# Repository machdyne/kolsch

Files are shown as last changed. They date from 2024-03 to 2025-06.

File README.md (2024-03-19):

# Kölsch Computer

Kölsch is an FPGA computer based on the GateMate A1.

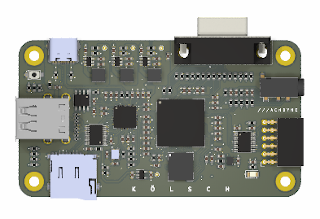
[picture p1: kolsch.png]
Kölsch Computer


This repo contains schematics, PCB layouts, pinouts, a 3D-printable case, example gateware and documentation.

Find more information on the [Kölsch product page](https://machdyne.com/product/kolsch-computer/).

## Programming Kölsch 

Kölsch can be programmed over USB-C or by copying gateware to a MicroSD card. The FPGA is configured by the onboard RP2040, which can load the configuration from onboard flash, a FAT-formatted MicroSD card or over the USB-JTAG bridge.

### JTAG

Program the FPGA configuration SRAM:

```
openFPGALoader -c dirtyJtag image.bit
```

## Examples

In order to build the examples, first edit rtl/config.mk and set the paths to the location of your toolchain. You can download the toolchain from [Cologne Chip](https://colognechip.com).

You can build each example with:

```
$ make && make impl
```

### 3.5mm TRRS Audio Jack

| Pin | Signal |
| --- | --- |
| T | Left Audio |
| R1 | Right Audio |
| R2 | Composite Video |
| S | GND |

## Resources

 * [fpga-dac audio player](https://github.com/machdyne/fpga-dac)

## Board Revisions

| Revision | Notes |
| --- | ----- |
| V2 | Initial production version |

## Funding

This project was partially funded through the NGI0 Entrust Fund, a fund established by NLnet with financial support from the European Commission's Next Generation Internet programme.

## License

This project is released under the [CERN-OHL-P](LICENSE.txt) license.

Note: You can use these designs for commercial purposes but we ask that instead of producing exact clones, that you either replace our trademarks and logos with your own or add your own next to ours.

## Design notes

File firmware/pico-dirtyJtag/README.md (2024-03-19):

# PICO-DIRTYJTAG

This code allows the Pico to become a JTAG cable.  It uses the PIO unit to produce and capture the JTAG signals.  This is a port of the excellent [DirtyJtag project](https://github.com/jeanthom/DirtyJTAG)

An additional feature provides a bridge to an external UART.  This is often useful when the target provides debugging output or a console over a UART.

<<<<<<< HEAD
| Pin name | Pico GPIO | Werkzeug GPIO |
|:---|:---|:---|
| TDI | GPIO16 | GPIO1 |
| TDO | GPIO17 | GPIO2 |
| TCK | GPIO18 | GPIO0 |
| TMS | GPIO19 | GPIO3 |
| RST | GPIO20 | GPIO4 |
| TRST | GPIO21 | GPIO5 |
=======
## Pinout
>>>>>>> 737c7b169514ec51a2ec9919f7796557875f9240

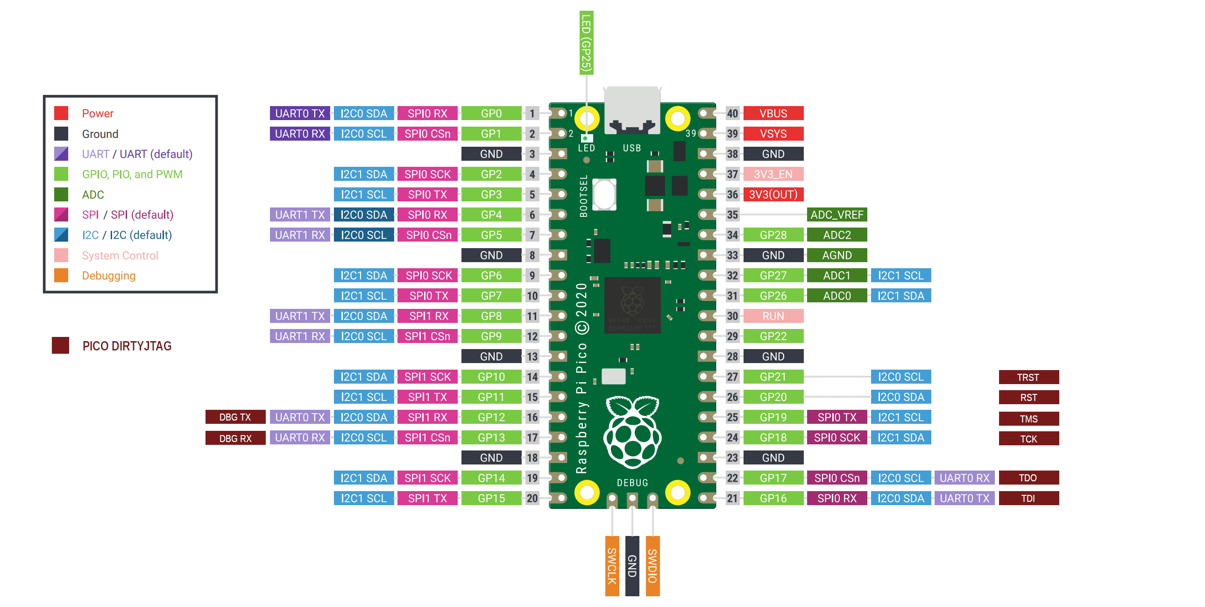
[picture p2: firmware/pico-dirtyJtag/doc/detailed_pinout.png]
Pinout image


| Pin name | GPIO | Pico Pin Number |
|:---|:---| - |
| TDI | GPIO16 | 21 |
| TDO | GPIO17 | 22 |
| TCK | GPIO18 | 24 |
| TMS | GPIO19 | 25 |
| RST | GPIO20 | 26 |
| TRST | GPIO21 | 27 |
| DBG TX | GPIO12 | 16 |
| DBG RX | GPIO13 | 17 |

## Configuration

Other configurations and RP2040 boards are supported.  

In `dirtyJtagConfig.h`, select the board you want to use, or define a new one.

``` C
#define BOARD_TYPE BOARD_PICO
//#define BOARD_TYPE BOARD_ADAFRUIT_ITSY
//#define BOARD_TYPE BOARD_SPOKE_RP2040
//#define BOARD_TYPE BOARD_WERKZEUG
//#define BOARD_TYPE BOARD_QMTECH_RP2040_DAUGHTERBOARD
```

The following values control where the code expects to find functionality.  Of course, not all pins can can be used for all functions.  Take care, especially with the UART pins, to ensure compatibility.

``` C
#define PIN_TDI 16 
#define PIN_TDO 17
#define PIN_TCK 18
#define PIN_TMS 19
#define PIN_RST 20
#define PIN_TRST 21

#define LED_INVERTED   0
#define PIN_LED_TX     25
#define PIN_LED_ERROR  25
#define PIN_LED_RX     25

#define PIN_UART       uart0
#define PIN_UART_TX    12
#define PIN_UART_RX    13
```

If the CDC to UART bridge is not required, or interfers in any way, it can be disabled by setting `USB_CDC_UART_BRIDGE` to 0

``` C
#define USB_CDC_UART_BRIDGE  0
```

See the `dirtyJtagConfig.h` file for these and other configuration options.

## Building pico-dirtyJtag

Follow [the instructions](https://github.com/raspberrypi/pico-sdk) for installing the official Raspberry Pi Pico SDK, then clone this repository and use the following commands:

```
mkdir -p build
cd build
cmake ..     # or for Werkzeug: cmake -DWERKZEUG=ON ..
make
```

If everything succeeds you should have a `dirtyJtag.uf2` file that you can directly upload to the Pi Pico.

## JTAG Usage

Once the board is running `pico-dirtyJtag` and connected to your host you will see a new USB device

```
$ lsusb
...
Bus 003 Device 112: ID 1209:c0ca Generic Jean THOMAS DirtyJTAG
...
```

You can connect to JTAG functionality using `UrJTAG`, `openFPGALoader` or other JTAG tools.  Depending on how your system is set up, you may have to run these commands as root.

For example, using `openFPGALoader`, the following command will connect to the Pico and read the IDCODE from the attached device:

```
> sudo openFPGALoader --cable dirtyJtag --detect
Jtag frequency : requested 6000000Hz -> real 6000000Hz
index 0:
	idcode 0x1112043
	manufacturer lattice
	family ECP5
	model  LFE5UM-45
	irlength 8
```

`UrTag` use is similar:

```
$ sudo jtag

UrJTAG 2021.03 #d9a2943f
Copyright (C) 2002, 2003 ETC s.r.o.
Copyright (C) 2007, 2008, 2009 Kolja Waschk and the respective authors

UrJTAG is free software, covered by the GNU General Public License, and you are
welcome to change it and/or distribute copies of it under certain conditions.
There is absolutely no warranty for UrJTAG.

warning: UrJTAG may damage your hardware!
Type "quit" to exit, "help" for help.

jtag> cable dirtyjtag
jtag> detect
IR length: 8
Chain length: 1
Device Id: 01000001000100010010000001000011 (0x41112043)
  Manufacturer: Lattice Semiconductors (0x043)
  Part(0):      LFE5U-45F-CABGA256 (0x1112)
  Stepping:     0
  Filename:     /usr/local/share/urjtag/lattice/lfe5u-45f-cabga256/lfe5u-45f-cabga256
jtag> 
```

## Debug UART

Once connected, a new port appears as an additional USB interface.  This port can be opened from a terminal emulation program or by custom code.

```
$ ls -la /dev/tty*
...
crw-rw---- 1 root  dialout 166,  0 May 28 08:25 /dev/ttyACM0
...
```

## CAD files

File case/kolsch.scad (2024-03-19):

/*
 * Kölsch Case
 * Copyright (c) 2023 Lone Dynamics Corporation. All rights reserved.
 *
 * required hardware:
 *  - 4 x M3 x 25mm countersunk bolts
 *  - 4 x M3 nuts
 *
 */

$fn = 100;

board_width = 50;
board_length = 90;
board_height = 1.6;
board_spacing = 2;

wall = 1.5;

top_height = 19;
bottom_height = 6;

mdq_board();

translate([0,0,15])
	mdq_case_top();

translate([0,0,-15])
	mdq_case_bottom();

module mdq_board() {
	
	difference() {
		color([0,0.5,0])
			roundedcube(board_width,board_length,board_height, 5);
		translate([5, 5, -1]) cylinder(d=3.2, h=10);
		translate([5, 85, -1]) cylinder(d=3.2, h=10);
		translate([85, 5, -1]) cylinder(d=3.2, h=10);
		translate([85, 85, -1]) cylinder(d=3.2, h=10);
	}	
	
}

module mdq_case_top() {

	difference() {
				
		union() {
			color([0.5,0.5,0.5]) {
				roundedcube(board_width+(wall*2),board_length+(wall*2),top_height, 5);
	//			translate([-1,45,0]) cube([board_width+5, 5,16]);
	//			translate([-1,65,0]) cube([board_width+5, 5,16]);
	//			translate([-1,55,0]) cube([board_width+5, 5,16]);
	//			translate([-1,45,0]) cube([board_width+5, 5,16]);
	//			translate([50/2-10,-1,0]) cube([5, board_length+5,16]);
	//			translate([50/2-1.25,-1,0]) cube([5, board_length+5,16]);
			}
		}
		
		// cutouts
			
		translate([2,9.5,-2])
			roundedcube(board_width-1.25,board_length-16,18.75,2.5);

		translate([9.5,3,-2])
			roundedcube(board_width-16,board_length-3,10.25,2.5);
		
		translate([wall, wall, 0]) {

			// vents
			translate([25-12.5,75-0.5,0]) cube([25,1,20]);
			translate([25-12.5,65-0.5,0]) cube([25,1,20]);
			translate([25-12.5,55-0.5,0]) cube([25,1,20]);

			translate([-5,55-0.5,5]) cube([10,1,10]);
			translate([-5,45-0.5,5]) cube([10,1,10]);
			translate([-5,35-0.5,5]) cube([10,1,10]);
			translate([-5,25-0.5,5]) cube([10,1,10]);
			translate([-5,15-0.5,5]) cube([10,1,10]);
			
			translate([45,65-0.5,5]) cube([10,1,10]);
			translate([45,60-0.5,5]) cube([10,1,10]);
			translate([45,55-0.5,5]) cube([10,1,10]);
			translate([45,50-0.5,5]) cube([10,1,10]);
			translate([45,45-0.5,5]) cube([10,1,10]);
						
			
			// VGA
			translate([30,90-65.29-(31/2),-1]) cube([30,31,12.5+1]);
		
			// PMOD
			translate([50-32.5-(16/2),-5,-1]) cube([16,30,5+1]);
			
			// audio jack
			translate([50-15-(6.2/2),-5,-1]) cube([6.2,30,5+1]);

			// USBC
			translate([30,90-14.325-(9.5/2),-1]) cube([30,9.5,3.5+1]);
			
			// USBA
			translate([25-(16/2),70,0]) cube([16,50,15.7+1]);
		
			// SD
			translate([-5,90-17.5-(15/2),-1]) cube([30,15,2+1]);

			// bolt holes
			translate([5, 5, -21]) cylinder(d=3.5, h=40);
			translate([5, 85, -21]) cylinder(d=3.5, h=40);
			translate([45, 5, -20]) cylinder(d=3.5, h=40);
			translate([45, 85, -21]) cylinder(d=3.5, h=40);

			// flush mount bolt holes
			translate([5, 5, top_height-1.5]) cylinder(d=5.25, h=4);
			translate([5, 85, top_height-1.5]) cylinder(d=5.25, h=4);
			translate([45, 5, top_height-1.5]) cylinder(d=5.25, h=4);
			translate([45, 85, top_height-1.5]) cylinder(d=5.25, h=4);
							
			// kolsch text
			rotate(270)
				translate([-25,22.5,top_height-0.5])
					linear_extrude(1)
						text("K Ö L S C H", size=5, halign="center",
							font="Ubuntu:style=Bold");

		}
		
	}	
}

module mdq_case_bottom() {
	
	difference() {
		color([0.5,0.5,0.5])
			roundedcube(board_width+(wall*2),board_length+(wall*2),bottom_height, 5);
		
		// cutouts
		translate([3,10,1.5])
			roundedcube(board_width-3,board_length-17,10,2.5);
				
		translate([10.5,2.5,1.5])
			roundedcube(board_width-17.5,board_length-2,10,2.5);

		translate([wall, wall, 0]) {
			
		// board cutout
		translate([0,0,bottom_height-board_height])
			roundedcube(board_width+0.2,board_length+0.2,board_height+1,2.5);

		translate([wall, wall, 0]) {

			// USBC
			translate([38.5,53.8-(9.5/2),5]) cube([10,9.5,10.5+1]);
			
		}

		// bolt holes
		translate([5, 5, -11]) cylinder(d=3.2, h=25);
		translate([5, 85, -11]) cylinder(d=3.2, h=25);
		translate([45, 5, -11]) cylinder(d=3.2, h=25);
		translate([45, 85, -11]) cylinder(d=3.2, h=25);

		// nut holes
		translate([5, 5, -1]) cylinder(d=7, h=4, $fn=6);
		translate([5, 85, -1]) cylinder(d=7, h=4, $fn=6);
		translate([45, 5, -1]) cylinder(d=7, h=4, $fn=6);
		translate([45, 85, -1]) cylinder(d=7, h=4, $fn=6);

		}
		
	}	
}

// https://gist.github.com/tinkerology/ae257c5340a33ee2f149ff3ae97d9826
module roundedcube(xx, yy, height, radius)
{
    translate([0,0,height/2])
    hull()
    {
        translate([radius,radius,0])
        cylinder(height,radius,radius,true);

        translate([xx-radius,radius,0])
        cylinder(height,radius,radius,true);

        translate([xx-radius,yy-radius,0])
        cylinder(height,radius,radius,true);

        translate([radius,yy-radius,0])
        cylinder(height,radius,radius,true);
    }
}

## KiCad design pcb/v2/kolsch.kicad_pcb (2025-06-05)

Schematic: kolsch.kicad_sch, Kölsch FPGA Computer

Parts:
C1, C2, C3, C12, C16, C18, C19, C27, C28, C38, C39, C48, C49, C69, C70: 2.2uF; C_0603_1608Metric
C4, C5, C6, C21, C22, C29, C30, C41, C42, C50, C51, C75, C76: 470nF; C_0603_1608Metric
C7: 220nF; C_0402_1005Metric
C8, C9, C10, C11, C15, C17, C23, C24, C31, C32, C33, C34, C35, C43, C44, C45, C46, C47, C52, C53, C55, C56, C78, C79, C80, C81, C103, C104, C105, C106, C107: 100nF; C_0402_1005Metric
C13, C14, C25, C26: 10nF; C_0402_1005Metric
C20, C36, C37, C58, C59, C61, C62, C64, C65, C66, C67, C68, C71, C74, C77, C82, C84, C86, C87: 100nF; C_0603_1608Metric
C40, C72, C73, C97, C98, C101: 10uF; C_0603_1608Metric
C54, C57: 15pF; C_0603_1608Metric
C60, C63, C83, C85, C88: 1uF; C_0603_1608Metric
C89, C90, C91: 4.7uF; C_0603_1608Metric
C92: 10uF; R_0603_1608Metric
C93: 100nF; R_0603_1608Metric
C94, C95, C96: 10pF; C_0603_1608Metric
C99, C100, C102: 22uF; C_0603_1608Metric
C109, C110: 10uF; C_0402_1005Metric
D1: LED; LED_1206_3216Metric
FB3, FB4, FB5: Ferrite_Bead; R_0603_1608Metric
H1, H2, H3, H4: MountingHole_Pad; MountingHole_3.2mm_M3_Pad
J1: TYPE-C-31-M-12-FIXED; USB_C_Receptacle_HRO_TYPE-C-31-M-12-BIG-PADS-PASTE; PARTREV A
J2: USB_A_Stacked; USB_A_Wuerth_61400826021_Horizontal_Stacked
J3: AudioJack4; Jack_3.5mm_PJ320D_Horizontal
J4: MICROSD; SDCARD
L1, L2, L3: 2.2uH; L_Taiyo-Yuden_MD-4040
PMOD1: PMOD-Device-x2-Type-1A-GPIO; PMOD_2x06_HOST
R1, R3, R4, R5, R8: 4K7; R_0603_1608Metric
R2, R10: 5K1; R_0603_1608Metric
R6, R7: 27R; R_0603_1608Metric
R9, R17, R18, R26, R27, R28, R29, R40, R41: 0R; LD-NETTIE-0603
R11, R12, R20, R21: 15K; R_0402_1005Metric
R13, R14, R15, R16: 22R; R_0402_1005Metric
R19, R58, R65: 200K; R_0603_1608Metric
R30, R35, R38, R45, R49, R53: 1K; R_0603_1608Metric
R31, R32, R63, R64: 100R; R_0603_1608Metric
R33, R42, R43, R47, R51: 270R; R_0603_1608Metric
R34, R44, R48, R52: 536R; R_0603_1608Metric
R36: 2K; R_0603_1608Metric
R37: 10K; R_0603_1608Metric
R39: 33R; R_0603_1608Metric
R46, R50, R54: 2K2; R_0603_1608Metric
R55, R56, R57: 68R; R_0603_1608Metric
R59, R60, R61, R62: 20K; R_0603_1608Metric
R66: 44K2; R_0603_1608Metric
R67: 150K; R_0603_1608Metric
R68: 47K; R_0603_1608Metric
R69: 100K; R_0603_1608Metric
R70: 120K; R_0603_1608Metric
R73: 22R; R_0603_1608Metric
SW1: BOOT; Button_2P_3x4mm
TP1: TP_PWR1V8; TestPoint_THTPad_D1.0mm_Drill0.5mm
TP2: TP_PWR3V3; TestPoint_THTPad_D1.0mm_Drill0.5mm
TP3: TP_PWR2V5; TestPoint_THTPad_D1.0mm_Drill0.5mm
TP4: TP_PWR1V1; TestPoint_THTPad_D1.0mm_Drill0.5mm
U1: CCGM1A1; BGA-324_15.0x15.0mm_Layout18x18_P0.8mm_Ball0.5mm_Pad0.4mm_N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
U2: W989D6DBGX6; W989D6DB; PARTREV A05
U3, U8: LSF0108PWR; TSSOP-20_4.4x6.5mm_P0.65mm
U4: RP2040; RP2040-QFN-56-OFFICIAL; PARTREV 1.6.1
U5: AT25FF321A-SSHN-B; SOIC-8_3.9x4.9mm_P1.27mm
U6: 48MHz; OSC_KC2016Z13.5600C1KX00
U7: NCP164ASN180T1G; SOT-23-5
U9, U10, U11: TLV62569DDC; SOT-23-6
VGA1: DB15_Female_MountingHoles; DSUB-15-HD_Female_Horizontal_P2.29x1.98mm_EdgePinOffset3.03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
Y1: ECS-80-12-33-JGN-TR-12MHZ; XTAL_ECS-240-8-33-AGN-TR

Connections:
/AUDIO_L: R31.1, U1.A9 (IO_NB_B0)
/AUDIO_LC: C72.1, J3.T
/AUDIO_R: R32.1, U1.B9 (IO_NB_A0)
/AUDIO_RC: C73.1, J3.R1
/BOOT: R38.1, SW1.1
/CDONE: U1.V3 (IO_WA_B2/CFG_DONE), U4.27 (GPIO16)
/CFAILED: R1.2, U1.V2 (IO_WA_A2/~CFG_FAILED), U4.28 (GPIO17)
/CFG_MD2: U1.U4 (CFG_MD2/IO_WA_A1), U4.18 (GPIO15)
/CFG_MD3: U1.V4 (CFG_MD3/IO_WA_B1), U4.17 (GPIO14)
/CLK48: U1.N14 (CLK0/IO_SB_A8), U6.3 (CLK)
/CRESET: U1.T15 (~RESET), U4.11 (GPIO8)
/CSD_MISO: U1.E2 (IO_WC_B3), U3.6 (A4), U4.6 (GPIO4)
/CSD_MOSI: U1.E1 (IO_WC_A3), U3.5 (A3), U4.9 (GPIO7)
/CSD_SCK: U1.E3 (IO_WC_A4), U3.4 (A2), U4.8 (GPIO6)
/CSD_SS: U1.D2 (IO_WC_B5), U3.3 (A1), U4.7 (GPIO5)
/CUSB1_DN: U1.H2 (IO_WB_B7), U3.10 (A8), U4.13 (GPIO10)
/CUSB1_DP: U1.H1 (IO_WB_A7), U3.9 (A7), U4.14 (GPIO11)
/CUSB2_DN: U1.K2 (IO_WB_B5), U3.8 (A6), U4.15 (GPIO12)
/CUSB2_DP: U1.K1 (IO_WB_A5), U3.7 (A5), U4.16 (GPIO13)
/DRAM_A0: U1.K18 (IO_EA_A2), U2.H7 (A0)
/DRAM_A1: U1.P18 (IO_SB_B2), U2.H8 (A1)
/DRAM_A2: U1.N15 (IO_SB_B8), U2.J8 (A2)
/DRAM_A3: U1.K17 (IO_EA_B2), U2.J7 (A3)
/DRAM_A4: U1.M14 (IO_EA_B0), U2.J3 (A4)
/DRAM_A5: U1.M15 (IO_EA_A0), U2.J2 (A5)
/DRAM_A6: U1.P15 (IO_SB_B6), U2.H3 (A6)
/DRAM_A7: U1.M17 (IO_SB_A3), U2.H2 (A7)
/DRAM_A8: U1.L16 (IO_EA_A1), U2.H1 (A8)
/DRAM_A9: U1.U18 (IO_SB_B0), U2.G3 (A9)
/DRAM_A10: U1.P17 (IO_SB_A2), U2.H9 (A10)
/DRAM_A11: U1.U17 (IO_SB_A0), U2.G2 (A11)
/DRAM_A12: U1.L15 (IO_EA_B1), U2.G1 (A12)
/DRAM_BS0: U1.J17 (IO_EA_B4), U2.G7 (BA0)
/DRAM_BS1: U1.R18 (IO_SB_B1), U2.G8 (BA1)
/DRAM_CAS: U1.M18 (IO_SB_B3), U2.F7 (~CAS)
/DRAM_CKE: U1.R10 (IO_SA_A7), U2.F3 (CKE)
/DRAM_CLK: U1.R9 (IO_SA_A6), U2.F2 (CLK)
/DRAM_CS: U1.R17 (IO_SB_A1), U2.G9 (~CS)
/DRAM_DQ0: U1.V8 (IO_SA_B5), U2.A8 (DQ0)
/DRAM_DQ1: U1.T8 (IO_SA_B4), U2.B9 (DQ1)
/DRAM_DQ2: U1.U8 (IO_SA_A5), U2.B8 (DQ2)
/DRAM_DQ3: U1.P13 (IO_SB_B7), U2.C9 (DQ3)
/DRAM_DQ4: U1.T10 (IO_SA_B7), U2.C8 (DQ4)
/DRAM_DQ5: U1.P14 (CLK2/IO_SB_A6), U2.D9 (DQ5)
/DRAM_DQ6: U1.T9 (IO_SA_B6), U2.D8 (DQ6)
/DRAM_DQ7: U1.V10 (IO_SA_B8), U2.E9 (DQ7)
/DRAM_DQ8: U1.R7 (IO_SA_A2), U2.E1 (DQ8)
/DRAM_DQ9: U1.R8 (IO_SA_A4), U2.D2 (DQ9)
/DRAM_DQ10: U1.T7 (IO_SA_B2), U2.D1 (DQ10)
/DRAM_DQ11: U1.V5 (IO_SA_B0), U2.C2 (DQ11)
/DRAM_DQ12: U1.U5 (IO_SA_A0), U2.C1 (DQ12)
/DRAM_DQ13: U1.V7 (IO_SA_B3), U2.B2 (DQ13)
/DRAM_DQ14: U1.T6 (IO_SA_B1), U2.B1 (DQ14)
/DRAM_DQ15: U1.U7 (IO_SA_A3), U2.A2 (DQ15)
/DRAM_LDQM: U1.U10 (IO_SA_A8), U2.E8 (LDQM)
/DRAM_RAS: U1.R14 (IO_SB_B5), U2.F8 (~RAS)
/DRAM_UDQM: U1.R6 (IO_SA_A1), U2.F1 (UDQM)
/DRAM_WE: U1.R13 (CLK3/IO_SB_A5), U2.F9 (~WE)
/JTAG_TCK: R3.2, U1.R3 (JTAG_TCK/IO_WA_A5), U4.29 (GPIO18)
/JTAG_TDI: R5.2, U1.T2 (JTAG_TDI/IO_WA_A4), U4.31 (GPIO20)
/JTAG_TDO: R8.2, U1.U2 (JTAG_TDO/IO_WA_B3), U4.32 (GPIO21)
/JTAG_TMS: R4.2, U1.T3 (JTAG_TMS/IO_WA_B4), U4.30 (GPIO19)
/LED: R42.1, U1.A12 (IO_NB_B4)
/PMOD_A1: U1.D17 (IO_EB_B2), U8.3 (A1)
/PMOD_A1C: PMOD1.1 (IOA0), U8.18 (B1)
/PMOD_A2: U1.D18 (IO_EB_A2), U8.4 (A2)
/PMOD_A2C: PMOD1.2 (IOA1), U8.17 (B2)
/PMOD_A3: U1.E15 (IO_EB_B3), U8.5 (A3)
/PMOD_A3C: PMOD1.3 (IOA2), U8.16 (B3)
/PMOD_A4: U1.E16 (IO_EB_A3), U8.6 (A4)
/PMOD_A4C: PMOD1.4 (IOA3), U8.15 (B4)
/PMOD_A7: U1.F18 (IO_EB_A0), U8.7 (A5)
/PMOD_A7C: PMOD1.7 (IOB0), U8.14 (B5)
/PMOD_A8: U1.F17 (IO_EB_B0), U8.8 (A6)
/PMOD_A8C: PMOD1.8 (IOB1), U8.13 (B6)
/PMOD_A9: U1.F16 (IO_EB_A1), U8.9 (A7)
/PMOD_A9C: PMOD1.9 (IOB2), U8.12 (B7)
/PMOD_A10: U1.F15 (IO_EB_B1), U8.10 (A8)
/PMOD_A10C: PMOD1.10 (IOB3), U8.11 (B8)
/PWR1V0: C58.1, C61.1, C63.1, U4.23 (DVDD), U4.45 (VREG_VOUT), U4.50 (DVDD)
/PWR1V1: C1.2, C2.2, C4.2, C5.2, C9.2, C10.2, C13.2, C14.2, C18.2, C19.2, C20.2, C21.2, C22.2, C23.2, C24.2, C25.2, C26.2, C96.1, C99.1, C100.1, L3.2, R69.1, R73.2, TP4.1, U1.F9 (VDD), U1.G6 (VDD), U1.G8 (VDD), U1.G10 (VDD), U1.G12 (VDD), U1.H7 (VDD), U1.H9 (VDD), U1.H11 (VDD), U1.H13 (VDD), U1.J6 (VDD), U1.J8 (VDD), U1.J10 (VDD), U1.J12 (VDD), U1.K7 (VDD), U1.K9 (VDD), U1.K11 (VDD), U1.K13 (VDD), U1.L6 (VDD), U1.L8 (VDD), U1.L10 (VDD), U1.L12 (VDD), U1.M7 (VDD), U1.M9 (VDD), U1.M11 (VDD), U1.M13 (VDD), U1.N6 (VDD), U1.N8 (VDD), U1.N10 (VDD)
/PWR1V8: C84.1, C88.1, C103.2, C104.2, C105.2, C106.2, C107.2, C109.2, C110.2, R27.2, R28.2, R29.2, TP1.1, U2.A7 (VDDQ), U2.A9 (VDD), U2.B3 (VDDQ), U2.C7 (VDDQ), U2.D3 (VDDQ), U2.E7 (VDD), U2.J9 (VDD), U6.1 (INH), U6.4 (VCC), U7.5 (OUT)
/PWR2V5: C8.2, C16.2, C37.1, C60.1, C62.1, C64.1, C65.1, C68.1, C71.1, C74.1, C77.1, C82.1, C83.1, C87.1, C95.1, C98.1, L2.2, R1.1, R4.1, R5.1, R8.1, R9.2, R17.2, R18.2, R26.2, R40.2, R41.2, R67.1, TP3.1, U1.T14 (VDD_CLK), U3.2 (VREF_A), U4.1 (IOVDD), U4.10 (IOVDD), U4.22 (IOVDD), U4.26 (RUN), U4.33 (IOVDD), U4.42 (IOVDD), U4.43 (ADC_AVDD), U4.44 (VREG_VIN), U4.49 (IOVDD), U5.8 (VCC), U8.2 (VREF_A)
/PWR3V3: C59.1, C85.1, C92.1, C93.1, C94.1, C97.1, C101.1, J4.4 (VDD), L1.2, PMOD1.6 (VCC), PMOD1.12 (VCC), R19.1, R37.1, R58.1, R59.1, R60.1, R61.1, R62.1, R65.1, TP2.1, U4.48 (USB_VDD), U7.1 (IN), U7.3 (EN)
/PWR5V0: C89.1, C90.1, C91.1, FB3.1, FB4.1, FB5.1, U9.1 (EN), U9.4 (VIN), U10.1 (EN), U10.4 (VIN), U11.1 (EN), U11.4 (VIN)
/RP_QSPI_IO0: U4.53 (QSPI_SD0), U5.5 (DI(IO0))
/RP_QSPI_IO1: U4.55 (QSPI_SD1), U5.2 (DO(IO1))
/RP_QSPI_IO2: U4.54 (QSPI_SD2), U5.3 (IO2)
/RP_QSPI_IO3: U4.51 (QSPI_SD3), U5.7 (IO3)
/RP_QSPI_SCK: U4.52 (QSPI_SCLK), U5.6 (CLK)
/RP_QSPI_SS: R37.2, R38.2, U4.56 (QSPI_CSN), U5.1 (~CS)
/RSPI_MISO: U1.P1 (IO_WA_A7/SPI_D1), U4.40 (GPIO28/ADC2)
/RSPI_MOSI: U1.P2 (IO_WA_B7/SPI_D0), U4.39 (GPIO27/ADC1)
/RSPI_SCK: U1.N4 (IO_WA_B8/SPI_CLK), U4.38 (GPIO26/ADC0)
/RSPI_SS: U1.N3 (IO_WA_A8/~SPI_CS), U4.41 (GPIO29/ADC3)
/RUART_RX: U1.F3 (IO_WC_A2), U4.37 (GPIO25)
/RUART_TX: U1.G1 (IO_WC_A0), U4.36 (GPIO24)
/SD_MISO: J4.7 (DAT0), R62.2, U3.15 (B4)
/SD_MOSI: J4.3 (CMD), R60.2, U3.16 (B3)
/SD_SCK: J4.5 (CLK), R61.2, U3.17 (B2)
/SD_SS: J4.2 (DAT3/CD), R59.2, U3.18 (B1)
/SWCLK: U4.24 (SWCLK)
/SWD: U4.25 (SWD)
/USB1_CONN_DN: J2.2 (D1-), R14.1, R21.1
/USB1_CONN_DP: J2.3 (D1+), R13.1, R20.1
/USB1_DN: R14.2, U3.11 (B8)
/USB1_DP: R13.2, U3.12 (B7)
/USB2_CONN_DN: J2.6 (D2-), R12.1, R16.1
/USB2_CONN_DP: J2.7 (D2+), R11.1, R15.1
/USB2_DN: R16.2, U3.13 (B6)
/USB2_DP: R15.2, U3.14 (B5)
/USB_CONN_DN: J1.A7 (DN1), J1.B7 (DN2), R6.1
/USB_CONN_DP: J1.A6 (DP1), J1.B6 (DP2), R7.1
/USB_DN: R6.2, U4.46 (USB_DM)
/USB_DP: R7.2, U4.47 (USB_DP)
/VBUSC: FB3.2, FB4.2, J1.A4 (VBUS), J1.A9 (VBUS), J1.B4 (VBUS), J1.B9 (VBUS)
/VDD_EA: C39.2, C42.2, C44.2, C46.2, R27.1, U1.G14 (VDD_EA), U1.H17 (VDD_EA), U1.J14 (VDD_EA), U1.L14 (VDD_EA), U1.L17 (VDD_EA)
/VDD_EB: C38.2, C41.2, C43.2, C45.2, C47.2, R26.1, U1.A16 (VDD_EB), U1.B18 (VDD_EB), U1.E14 (VDD_EB), U1.E17 (VDD_EB), U1.F13 (VDD_EB)
/VDD_NA: C27.2, C29.2, C31.2, C33.2, C35.2, R17.1, U1.A5 (VDD_NA), U1.B7 (VDD_NA), U1.E6 (VDD_NA), U1.E8 (VDD_NA), U1.F7 (VDD_NA)
/VDD_NB: C28.2, C30.2, C32.2, C34.2, R18.1, U1.B10 (VDD_NB), U1.B13 (VDD_NB), U1.E10 (VDD_NB), U1.E12 (VDD_NB), U1.F11 (VDD_NB)
/VDD_PLL: C7.2, C12.2, C102.2, R73.1, U1.P16 (VDD_PLL)
/VDD_SA: C49.2, C51.2, C53.2, C56.2, R29.1, U1.P6 (VDD_SA), U1.P8 (VDD_SA), U1.P10 (VDD_SA), U1.U6 (VDD_SA), U1.U9 (VDD_SA)
/VDD_SB: C48.2, C50.2, C52.2, C55.2, R28.1, U1.N11 (VDD_SB), U1.N13 (VDD_SB), U1.N18 (VDD_SB), U1.R15 (VDD_SB), U1.T18 (VDD_SB)
/VDD_WA: C3.2, C6.2, C11.2, C15.2, C17.2, R9.1, U1.N5 (VDD_WA), U1.P3 (VDD_WA), U1.P5 (VDD_WA), U1.T1 (VDD_WA), U1.U3 (VDD_WA)
/VDD_WB: C70.2, C76.2, C79.2, C81.2, R41.1, U1.H5 (VDD_WB), U1.J2 (VDD_WB), U1.K5 (VDD_WB), U1.M2 (VDD_WB), U1.M5 (VDD_WB)
/VDD_WC: C69.2, C75.2, C78.2, C80.2, R40.1, U1.A2 (VDD_WC), U1.C2 (VDD_WC), U1.D5 (VDD_WC), U1.F2 (VDD_WC), U1.F5 (VDD_WC)
/VGA_B0: R51.2, U1.C9 (IO_NA_A8)
/VGA_B1: R52.2, U1.C8 (IO_NA_A6)
/VGA_B2: R53.2, U1.C7 (IO_NA_A5)
/VGA_B3: R54.2, U1.C6 (IO_NA_A3)
/VGA_BLUE: R51.1, R52.1, R53.1, R54.1, R57.2
/VGA_B_CONN: R57.1, VGA1.3
/VGA_G0: R47.2, U1.C5 (IO_NA_B2)
/VGA_G1: R48.2, U1.B8 (IO_NA_B7)
/VGA_G2: R49.2, U1.A8 (IO_NA_A7)
/VGA_G3: R50.2, U1.B6 (IO_NA_B4)
/VGA_GREEN: R47.1, R48.1, R49.1, R50.1, R56.2
/VGA_G_CONN: R56.1, VGA1.2
/VGA_HS: R63.2, U1.A3 (IO_NA_A0)
/VGA_HS_CONN: R63.1, VGA1.13
/VGA_R0: R43.2, U1.A6 (IO_NA_A4)
/VGA_R1: R44.2, U1.B5 (IO_NA_A2)
/VGA_R2: R45.2, U1.A4 (IO_NA_A1)
/VGA_R3: R46.2, U1.B4 (IO_NA_B1)
/VGA_RED: R43.1, R44.1, R45.1, R46.1, R55.2
/VGA_R_CONN: R55.1, VGA1.1
/VGA_VS: R64.2, U1.B3 (IO_NA_B0)
/VGA_VS_CONN: R64.1, VGA1.14
/VIDEO_C: J3.R2, R39.2
/VIDEO_D0: R33.1, U1.A17 (IO_EB_B5)
/VIDEO_D1: R34.1, U1.C18 (IO_EB_A4)
/VIDEO_D2: R35.1, U1.C17 (IO_EB_B4)
/VIDEO_D3: R36.1, U1.B15 (IO_EB_A8)
/XIN: C54.2, U4.20 (XIN), Y1.1 (IN/OUT)
/XOUT: R30.2, U4.21 (XOUT)
GND: C1.1, C2.1, C3.1, C4.1, C5.1, C6.1, C7.1, C8.1, C9.1, C10.1, C11.1, C12.1, C13.1, C14.1, C15.1, C16.1, C17.1, C18.1, C19.1, C20.1, C21.1, C22.1, C23.1, C24.1, C25.1, C26.1, C27.1, C28.1, C29.1, C30.1, C31.1, C32.1, C33.1, C34.1, C35.1, C36.2, C37.2, C38.1, C39.1, C40.2, C41.1, C42.1, C43.1, C44.1, C45.1, C46.1, C47.1, C48.1, C49.1, C50.1, C51.1, C52.1, C53.1, C54.1, C55.1, C56.1, C57.2, C58.2, C59.2, C60.2, C61.2, C62.2, C63.2, C64.2, C65.2, C66.2, C67.2, C68.2, C69.1, C70.1, C71.2, C74.2, C75.1, C76.1, C77.2, C78.1, C79.1, C80.1, C81.1, C82.2, C83.2, C84.2, C85.2, C86.2, C87.2, C88.2, C89.2, C90.2, C91.2, C92.2, C93.2, C97.2, C98.2, C99.2, C100.2, C101.2, C102.1, C103.1, C104.1, C105.1, C106.1, C107.1, C109.1, C110.1, D1.1 (K), H1.1, H2.1, H3.1, H4.1, J1.A1 (GND), J1.A12 (GND), J1.B1 (GND), J1.B12 (GND), J1.S1 (SHIELD), J1.S2 (SHIELD), J1.S3 (SHIELD), J1.S4 (SHIELD), J2.4 (GND1), J2.8 (GND2), J2.9 (Shield), J3.S, J4.6 (VSS), PMOD1.5 (GND), PMOD1.11 (GND), R2.2, R3.1, R10.2, R11.2, R12.2, R20.2, R21.2, R66.2, R68.2, R70.2, SW1.2, U1.A1 (GND), U1.A7 (GND), U1.A10 (GND), U1.A13 (GND), U1.A18 (GND), U1.B16 (GND), U1.C1 (GND), U1.E5 (GND), U1.E7 (GND), U1.E9 (GND), U1.E11 (GND), U1.E13 (GND), U1.E18 (GND), U1.F1 (GND), U1.F6 (GND), U1.F8 (GND), U1.F10 (GND), U1.F12 (GND), U1.F14 (GND), U1.G5 (GND), U1.G7 (GND), U1.G9 (GND), U1.G11 (GND), U1.G13 (GND), U1.H6 (GND), U1.H8 (GND), U1.H10 (GND), U1.H12 (GND), U1.H14 (GND), U1.H18 (GND), U1.J1 (GND), U1.J5 (GND), U1.J7 (GND), U1.J9 (GND), U1.J11 (GND), U1.J13 (GND), U1.K6 (GND), U1.K8 (GND), U1.K10 (GND), U1.K12 (GND), U1.K14 (GND), U1.L5 (GND), U1.L7 (GND), U1.L9 (GND), U1.L11 (GND), U1.L13 (GND), U1.L18 (GND), U1.M1 (GND), U1.M6 (GND), U1.M8 (GND), U1.M10 (GND), U1.M12 (GND), U1.M16 (GND), U1.N7 (GND), U1.N9 (GND), U1.N12 (GND), U1.N17 (GND), U1.P4 (GND), U1.P7 (GND), U1.P9 (GND), U1.R5 (CFG_MD0/IO_WA_A0), U1.R12 (GND), U1.R16 (GND), U1.T4 (GND), U1.T5 (CFG_MD1/IO_WA_B0), U1.T11 (GND), U1.T17 (GND), U1.U1 (POR_EN/IO_WA_A3), U1.U14 (GND), U1.U15 (GND), U1.U16 (GND), U1.V1 (GND), U1.V6 (GND), U1.V9 (GND), U1.V14 (GND), U1.V16 (GND), U1.V18 (GND), U2.A1 (VSS), U2.A3 (VSSQ), U2.B7 (VSSQ), U2.C3 (VSSQ), U2.D7 (VSSQ), U2.E3 (VSS), U2.J1 (VSS), U3.1 (GND), U4.19 (TESTEN), U4.57 (GND), U5.4 (GND), U6.2 (GND), U7.2 (GND), U8.1 (GND), U9.2 (GND), U10.2 (GND), U11.2 (GND), VGA1.0 (PAD), VGA1.5, VGA1.6, VGA1.7, VGA1.8, VGA1.10, Y1.2 (GND), Y1.4 (GND)
unnamed: C66.1, C72.2, R31.2
unnamed: C67.1, C73.2, R32.2
unnamed: D1.2 (A), R42.2
unnamed: J1.A5 (CC1), R2.1
unnamed: J1.B5 (CC2), R10.1
unnamed: C40.1, FB5.2, J2.1 (VBUS1), J2.5 (VBUS2)
unnamed: R33.2, R34.2, R35.2, R36.2, R39.1
unnamed: C36.1, R19.2, U3.19 (VREF_B), U3.20 (EN)
unnamed: C86.1, R58.2, U8.19 (VREF_B), U8.20 (EN)
unnamed: C94.2, R65.2, R66.1, U9.6 (FB)
unnamed: L1.1, U9.3 (SW)
unnamed: C95.2, R67.2, R68.1, U10.6 (FB)
unnamed: L2.1, U10.3 (SW)
unnamed: C96.2, R69.2, R70.1, U11.6 (FB)
unnamed: L3.1, U11.3 (SW)
unnamed: C57.1, R30.1, Y1.3 (OUT/IN)

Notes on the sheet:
MICROSD
EAST
WEST
LPSDR
AUDIO/VIDEO
UART1 TX
C1=15pF, C2=15pF, CL=12pF, Cstray=5, (C1*C2)/(C1+C2)+Cstray == CL
SPI0 CSn
FPGA
Kölsch
0.6 * (1 + (150/47)) = 2.514
SPI1 RX
SYSTEM CLOCK
PMOD
NORTH
SPI1 TX
UART1 RX
0.6 * (1 + (100/120)) = 1.0999 (SPEED mode)
SUPERVISOR
DUAL USB HOST PORTS
12-bit VGA DAC (RGB444)
SPI0 TX
SPI1 SCK
POWER
SPI0 RX
0.6 * (1 + (200/44.2)) = 3.314
SPI0 SCK
USB POWER / CONFIG
SOUTH

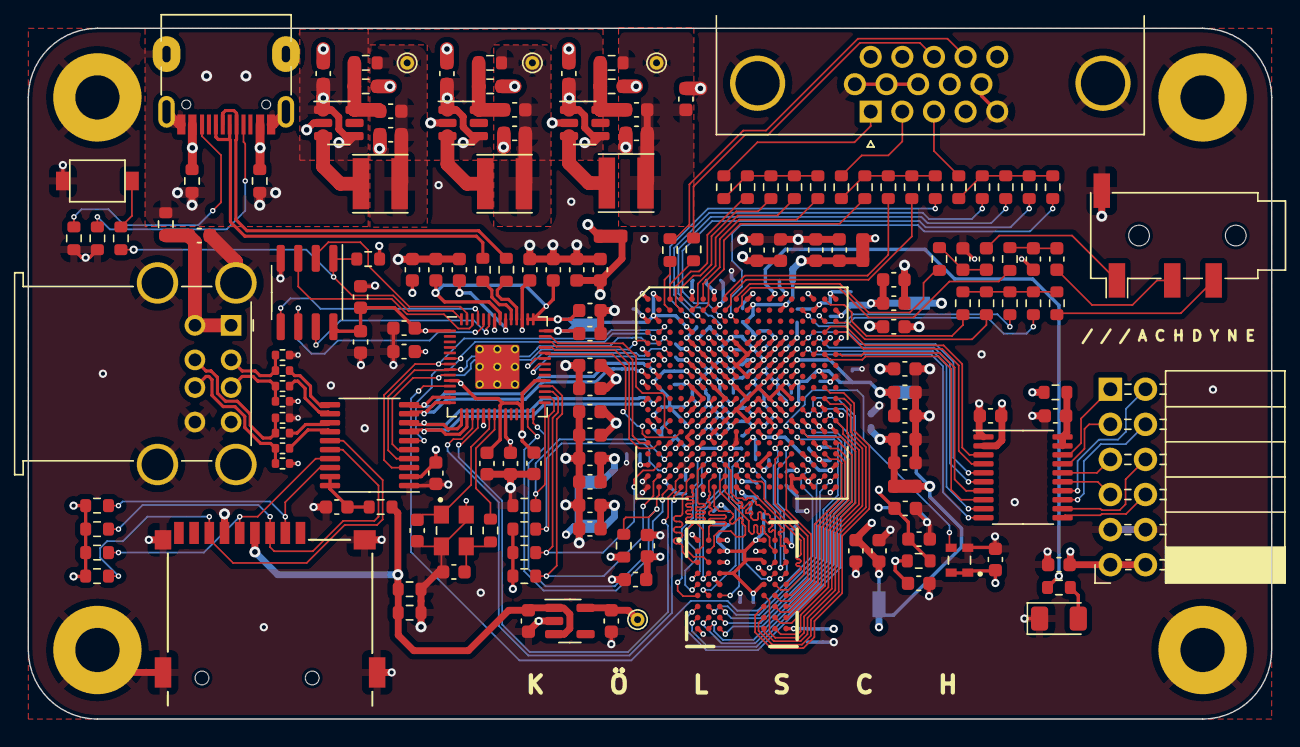
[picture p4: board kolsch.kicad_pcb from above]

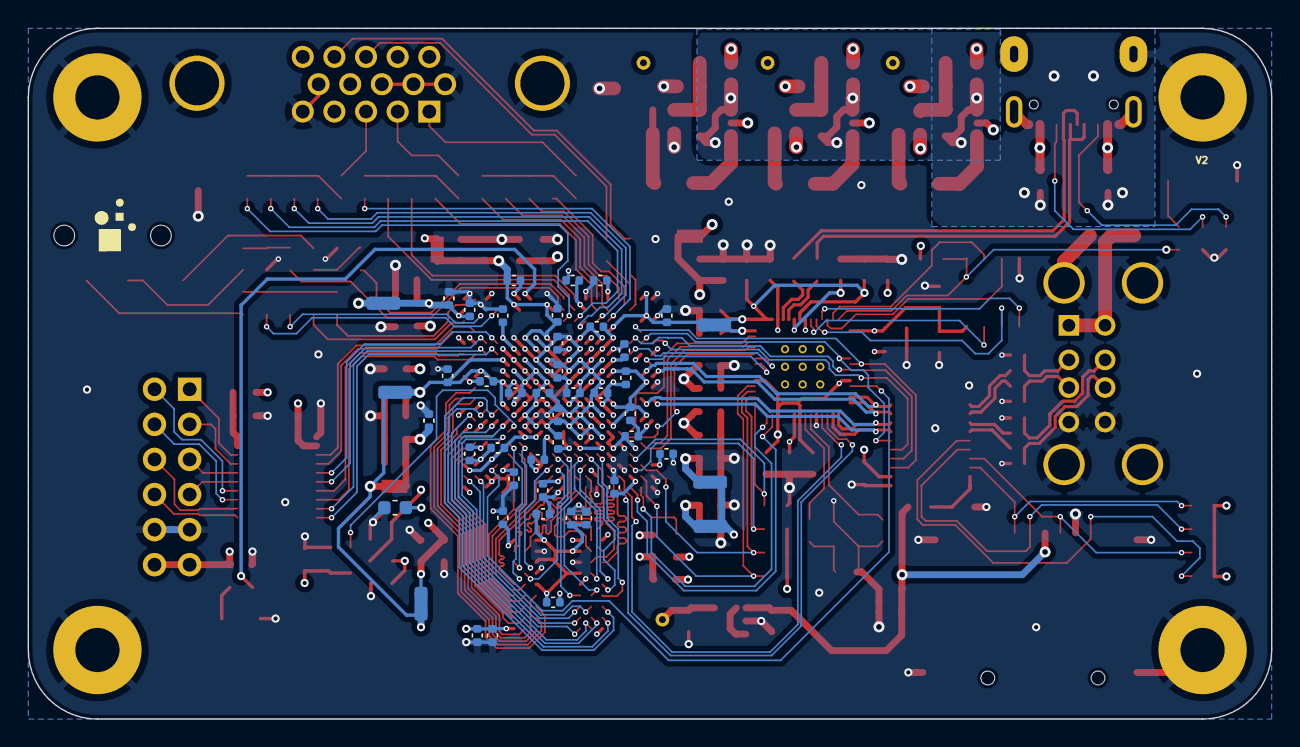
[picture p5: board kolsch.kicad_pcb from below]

Board: 4 copper layers, 90.0 x 50.0 mm, 210 parts (45 on the bottom side), 170 nets.

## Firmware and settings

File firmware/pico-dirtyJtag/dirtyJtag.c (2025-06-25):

#include <stdio.h>
#include "pico/stdlib.h"
#include "pico/binary_info.h"
#include "hardware/pio.h"
#include "pico/multicore.h"
#include "dirtyJtagConfig.h"
#include "pio_jtag.h"
#include "bsp/board.h"
#include "tusb.h"
#include "cmd.h"
#include "get_serial.h"
#include "hardware/clocks.h"
#include "hardware/structs/pll.h"
#include "hardware/structs/clocks.h"

#include "led.h"
#include "cdc_uart.h"

#define MULTICORE

void init_pins()
{
    bi_decl(bi_4pins_with_names(PIN_TCK, "TCK", PIN_TDI, "TDI", PIN_TDO, "TDO", PIN_TMS, "TMS"));
    #if !( BOARD_TYPE == BOARD_QMTECH_RP2040_DAUGHTERBOARD )
    bi_decl(bi_2pins_with_names(PIN_RST, "RST", PIN_TRST, "TRST"));
    #endif
}

pio_jtag_inst_t jtag = {
            .pio = pio0,
            .sm = 0
};

void djtag_init()
{
    init_pins();
    init_jtag(&jtag, 1000, PIN_TCK, PIN_TDI, PIN_TDO, PIN_TMS, 255, 255);

    gpio_init(PIN_CFG_MD2);
    gpio_init(PIN_CFG_MD3);
    gpio_init(PIN_CRESET);
    gpio_init(PIN_CDONE);
    gpio_init(PIN_CFAILED);

    gpio_set_dir(PIN_CFG_MD2, 1); // set as output
    gpio_set_dir(PIN_CFG_MD3, 1); // set as output
    gpio_set_dir(PIN_CRESET, 1); // set as output

    // enter JTAG mode
    gpio_put(PIN_CFG_MD2, 1);
    gpio_put(PIN_CFG_MD3, 1);

    // toggle CRESET
    gpio_put(PIN_CRESET, 0);
    sleep_ms(250);
    gpio_put(PIN_CRESET, 1);

}
typedef uint8_t cmd_buffer[64];
static uint wr_buffer_number = 0;
static uint rd_buffer_number = 0; 
typedef struct buffer_info
{
    volatile uint8_t count;
    volatile uint8_t busy;
    cmd_buffer buffer;
} buffer_info;

#define n_buffers (4)

buffer_info buffer_infos[n_buffers];

static cmd_buffer tx_buf;

void jtag_main_task()
{
#ifdef MULTICORE
    if (multicore_fifo_rvalid())
    {
        //some command processing has been done
        uint rx_num = multicore_fifo_pop_blocking();
        buffer_info* bi = &buffer_infos[rx_num];
        bi->busy = false;

    }
#endif
    if ((buffer_infos[wr_buffer_number].busy == false)) 
    {
        //If tud_task() is called and tud_vendor_read isn't called immediately (i.e before calling tud_task again)
        //after there is data available, there is a risk that data from 2 BULK OUT transaction will be (partially) combined into one
        //The DJTAG protocol does not tolerate this. 
        tud_task();// tinyusb device task
        if (tud_vendor_available())
        {
            led_rx( 1 );
            uint bnum = wr_buffer_number;
            uint count = tud_vendor_read(buffer_infos[wr_buffer_number].buffer, 64);
            if (count != 0)
            {
                buffer_infos[bnum].count = count;
                buffer_infos[bnum].busy = true;
                wr_buffer_number = wr_buffer_number + 1; //switch buffer
                if (wr_buffer_number == n_buffers)
                {
                    wr_buffer_number = 0; 
                }
#ifdef MULTICORE
                multicore_fifo_push_blocking(bnum);
#endif
            }
            led_rx( 0 );
        } else {
#if ( USB_CDC_UART_BRIDGE )           
            cdc_uart_task();
#endif
        }
    }
}

void jtag_task()
{
#ifndef MULTICORE
    jtag_main_task();
#endif
}

#ifdef MULTICORE
void core1_entry() {

    djtag_init();
    while (1)
    {
        uint rx_num = multicore_fifo_pop_blocking();
        buffer_info* bi = &buffer_infos[rx_num];
        assert (bi->busy);
        cmd_handle(&jtag, bi->buffer, bi->count, tx_buf);
        multicore_fifo_push_blocking(rx_num);
    }
 
}
#endif

void fetch_command()
{
#ifndef MULTICORE
    if (buffer_infos[rd_buffer_number].busy)
    {
        cmd_handle(&jtag, buffer_infos[rd_buffer_number].buffer, buffer_infos[rd_buffer_number].count, tx_buf);
        buffer_infos[rd_buffer_number].busy = false;
        rd_buffer_number++; //switch buffer
        if (rd_buffer_number == n_buffers)
        {
            rd_buffer_number = 0; 
        }
    }
#endif
}

//this is to work around the fact that tinyUSB does not handle setup request automatically
//Hence this boiler plate code
bool tud_vendor_control_xfer_cb(uint8_t rhport, uint8_t stage, tusb_control_request_t const * request)
{
    if (stage != CONTROL_STAGE_SETUP) return true;
    return false;
}

int main()
{
    board_init();
    usb_serial_init();
    tusb_init();

    led_init( LED_INVERTED, PIN_LED_TX, PIN_LED_RX, PIN_LED_ERROR );
#if ( USB_CDC_UART_BRIDGE )
    cdc_uart_init( PIN_UART, PIN_UART_RX, PIN_UART_TX );
#endif

#ifdef MULTICORE
    multicore_launch_core1(core1_entry);
#else 
    djtag_init();
#endif
    while (1) {
        jtag_main_task();
        fetch_command();//for unicore implementation
    }
}

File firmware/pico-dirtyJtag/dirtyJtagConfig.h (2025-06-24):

#ifndef DirtyJtagConfig_h
#define DirtyJtagConfig_h

// Set to 0 to disable USB-CDC-UART bridge
#define USB_CDC_UART_BRIDGE  1


#define BOARD_PICO           0
#define BOARD_ADAFRUIT_ITSY  1
#define BOARD_SPOKE_RP2040   2
#define BOARD_QMTECH_RP2040_DAUGHTERBOARD 3
#define BOARD_WERKZEUG       4
#define BOARD_KOLSCH         100

// Select the board type from the above
#define BOARD_TYPE BOARD_KOLSCH
//#define BOARD_TYPE BOARD_ADAFRUIT_ITSY
//#define BOARD_TYPE BOARD_SPOKE_RP2040
//#define BOARD_TYPE BOARD_WERKZEUG
//#define BOARD_TYPE BOARD_QMTECH_RP2040_DAUGHTERBOARD

// General mapping
// TDI  SPIO RX
// TDO  SPIO TX
// TCK  SPIO SCK
// TMS  SPIO CS
// RST  GPIO
// TRST GPIO

#if ( BOARD_TYPE == BOARD_PICO )

#define PIN_TDI 16 
#define PIN_TDO 17
#define PIN_TCK 18
#define PIN_TMS 19
#define PIN_RST 20
#define PIN_TRST 21

#define LED_INVERTED   0
#define PIN_LED_TX     25
#define PIN_LED_ERROR  25
#define PIN_LED_RX     25

#if ( USB_CDC_UART_BRIDGE )
#define PIN_UART       uart0
#define PIN_UART_TX    12
#define PIN_UART_RX    13
#endif // USB_CDC_UART_BRIDGE

#elif ( BOARD_TYPE == BOARD_ADAFRUIT_ITSY )

#define PIN_TDI 28 
#define PIN_TDO 27
#define PIN_TCK 26
#define PIN_TMS 29
#define PIN_RST 24
#define PIN_TRST 25

// no regular LEDs on the Itsy - it's a neopixel
#define LED_INVERTED   0
#define PIN_LED_TX     -1
#define PIN_LED_ERROR  -1
#define PIN_LED_RX     -1

#if ( USB_CDC_UART_BRIDGE )
#define PIN_UART       uart0
#define PIN_UART_TX    0
#define PIN_UART_RX    1
#endif // USB_CDC_UART_BRIDGE

#elif ( BOARD_TYPE == BOARD_SPOKE_RP2040 )

#define PIN_TDI 23 
#define PIN_TDO 20
#define PIN_TCK 22
#define PIN_TMS 21
#define PIN_RST 26
#define PIN_TRST 27

#define LED_INVERTED   1
#define PIN_LED_TX     16
#define PIN_LED_ERROR  17
#define PIN_LED_RX     18

#if ( USB_CDC_UART_BRIDGE )
#define PIN_UART       uart0
#define PIN_UART_TX    28
#define PIN_UART_RX    29
#endif // USB_CDC_UART_BRIDGE


#elif ( BOARD_TYPE == BOARD_WERKZEUG )

#define PIN_TDI 1
#define PIN_TDO 2
#define PIN_TCK 0
#define PIN_TMS 3
#define PIN_RST 4
#define PIN_TRST 5

#define LED_INVERTED   1
#define PIN_LED_TX     20
#define PIN_LED_ERROR  21
#define PIN_LED_RX     20

#if ( USB_CDC_UART_BRIDGE )
#define PIN_UART       uart0
#define PIN_UART_TX    28
#define PIN_UART_RX    29
#endif // USB_CDC_UART_BRIDGE

#elif ( BOARD_TYPE == BOARD_KOLSCH )

#define PIN_TCK 18
#define PIN_TDI 20
#define PIN_TDO 21
#define PIN_TMS 19

#define PIN_RST 8
#define PIN_TRST 9

#define PIN_CDONE		16
#define PIN_CFAILED	17
#define PIN_CRESET	8
#define PIN_CFG_MD2	15
#define PIN_CFG_MD3	14

#define LED_INVERTED   1
#define PIN_LED_TX     1
#define PIN_LED_ERROR  2
#define PIN_LED_RX     3

#if ( USB_CDC_UART_BRIDGE )
#define PIN_UART       uart1
#define PIN_UART_TX    24
#define PIN_UART_RX    25
#endif // USB_CDC_UART_BRIDGE


#elif ( BOARD_TYPE == BOARD_QMTECH_RP2040_DAUGHTERBOARD )

// in rp2040 daughterboard UART pins are connected to FPGA pins
// depending on the FPGA pin configuration there is a possibility
// of damage so these pins are not going to be setup
#define USB_CDC_UART_BRIDGE  0

#define PIN_TDI  16 
#define PIN_TDO  17
#define PIN_TCK  18
#define PIN_TMS  19
// in rp2040 daughterboard these pins are connected to FPGA pins
// depending on the FPGA pin configuration there is a possibility
// of damage so these pins are not going to be setup
// #define PIN_RST  X
// #define PIN_TRST X

#define LED_INVERTED   0
#define PIN_LED_TX     25
#define PIN_LED_ERROR  25
#define PIN_LED_RX     25

#endif // BOARD_TYPE

#endif // DirtyJtagConfig_h

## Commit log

2024-03-19 rename kicad files
    [kolsch.kicad_pcb, kolsch.kicad_sch]
2025-06-05 update schematics
    [kolsch.kicad_pcb, kolsch.kicad_sch]
2025-06-25 Toggle CRESET on jtag reset
    [dirtyJtag.c]

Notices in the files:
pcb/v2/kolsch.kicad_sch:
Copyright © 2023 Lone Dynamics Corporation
